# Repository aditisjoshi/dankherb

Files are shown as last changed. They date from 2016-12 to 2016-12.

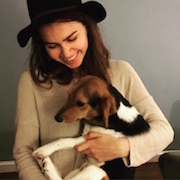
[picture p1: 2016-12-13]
website/images/ceceliaphoto.jpg

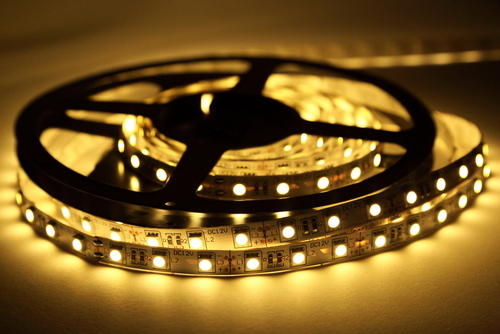
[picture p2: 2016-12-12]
website/images/lights.jpg

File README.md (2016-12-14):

# dankherb
### PoE project Fall 2016
December 6th, 2016

The following is the github repo for our final project for Principles of Engineering class Fall 2016 at Olin College of Engineering. Our project is an autonomous herb garden that takes care of your plants for you using a drip irrigation system and autonomous LED lighting system. The following are instructions for how to setup to use the project. 

## Do it yourself! (How to Run our Project)

### Getting the Code
Fork this repo. :)

### Running the Python Code (GUI)

#### dependencies 
The python GUI depends on the following libraries:

##### Python 
The code is programmed using Python 2.7. Use the instructions [here](https://www.python.org/downloads/) to download it if you do not have it.

##### Kivy
You can use `$pip install kivy` to download this package. 

###### A Note About Pygame
Kivy depends on Pygame, so if you do not have it, you can use `$pip install pygame` to download this package. 

##### Serial
You can use `$pip install pyserial` to download this package. 

#### To Run
In order to run the GUI, you must first run the Arduino code (reciever_control.ino) and then move over to python and run GardenaiApp.py. A window should appear that should give you information about the plants and their status. You can close the app when you are done with it.

##### A note about the serial name
You will need to change the name on the serial name depending on what your Arduino program names it. You should go to line 23 in the garden.py code and change the following line `ser = serial.Serial('/dev/cu.usbmodemFA131', 9600,timeout=5)` to whatever usbmodem name your Arduino has. 

### Running the Arduino Code 
In order to run the Arduino code you should run reciever_control.ino. You should attach the usb from the system into a port into your computer and change the port on your arduino IDE and then run the appropriate code. 

#### Reciever
The reciever code can be found in reciever_control.ino. This code controls everything for the water part of the system. It consists of an Arduino and an Adafruit motor shield. The motor shield controls the pump, using the Adafruit Motorshield library, by initalizing it as a motor. The four sensors that control the pump are in analog inputs 0-3. If the average of these values is below a certain threshold, then the pump turns off. 
This code also recieves control from the writer and then prints the 8 different sensor values (the 4 soil sensors and the 4 light sensors) to the serial monitor which the Python GUI code then reads to give the user the information.

#### Writer
The writer code can be found in writer_control.ino. This code controls everything for the light part of the system. The lights that we are using are individually adressable leds from Adafruit Neopixels. In order to control these we use the the Neopixel library. We are using DLI to control the lights. The code reads the light values from the four sensors in analog inputs 0-3. They take a running average of one sensor values and if that average is below the DLI threshold for that plant, the lights addressed to that plan turn on. 
This code also writes code to the reciever using the Wire library. 

## Website
The folder for the website includes the html, css, and images for the website. You can visit http://poe.olin.edu/2016/gardenai/ to see our working website in action.

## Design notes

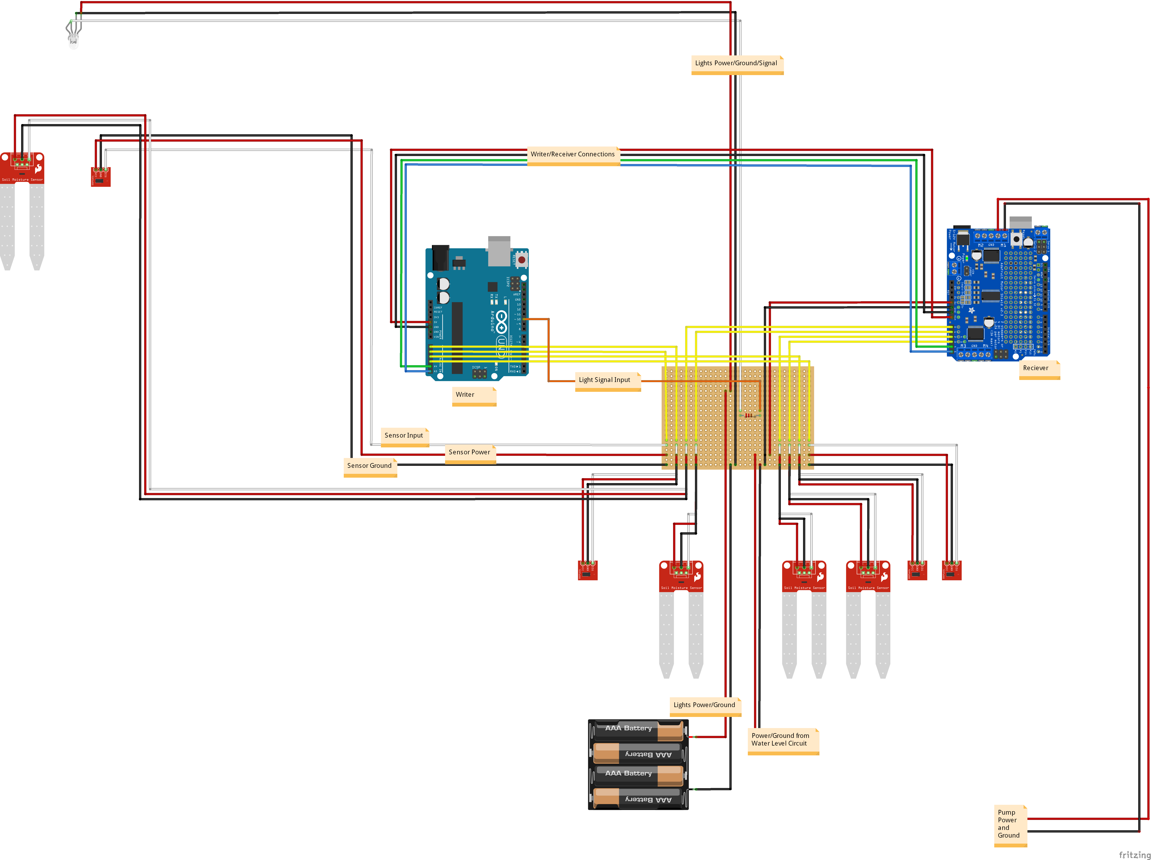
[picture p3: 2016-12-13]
website/images/overallCircuit.jpg

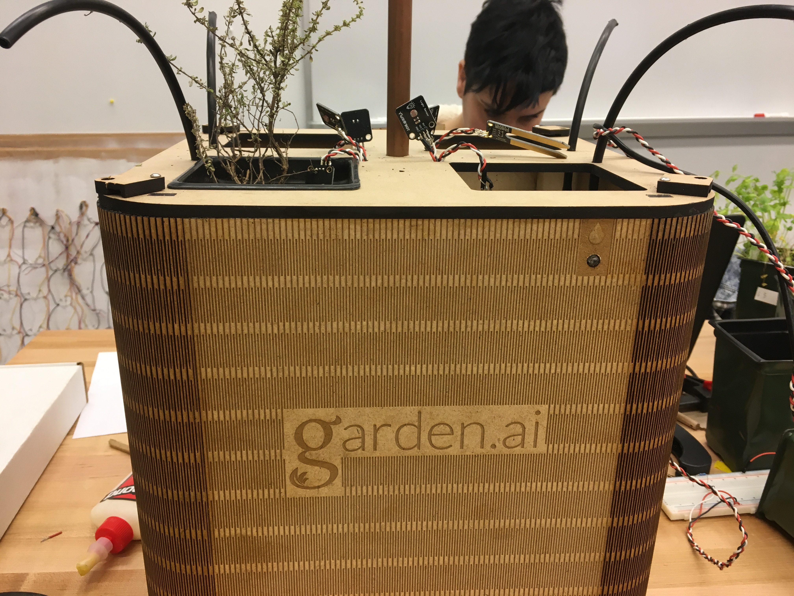
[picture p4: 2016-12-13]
website/images/gallery10.jpg

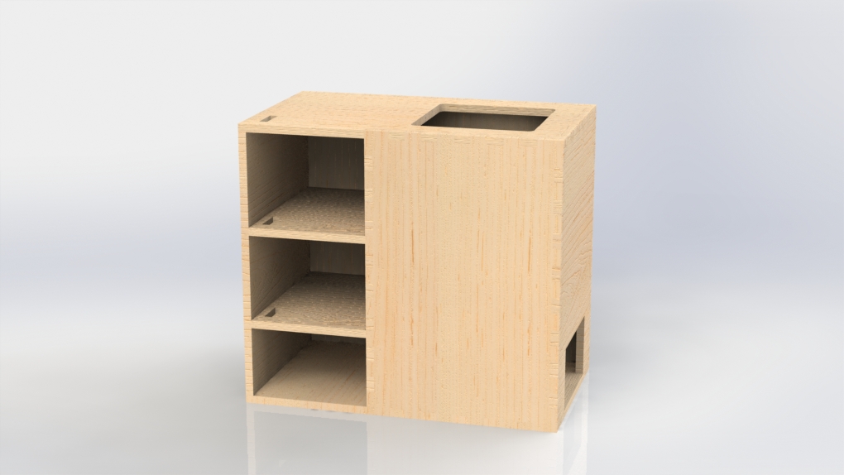
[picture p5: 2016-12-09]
website/images/gallery7.JPG

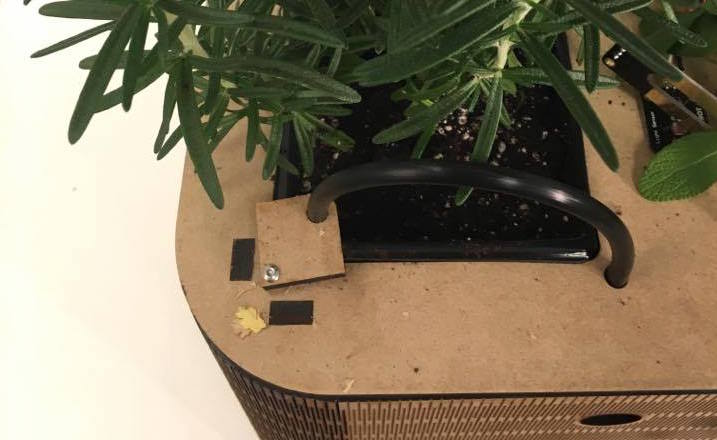
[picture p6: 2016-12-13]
website/images/irrigation.jpg

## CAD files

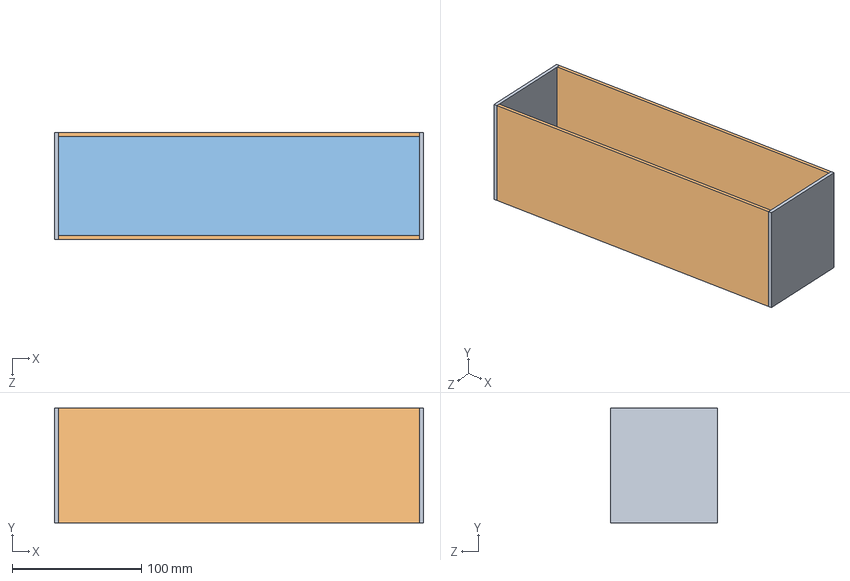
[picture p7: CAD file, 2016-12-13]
finalCadAndCutFiles/drainageresovoir/drainageresovoir.SLDASM
285.8 x 88.9 x 82.6 mm
front x 2
drsides x 2
drbottom

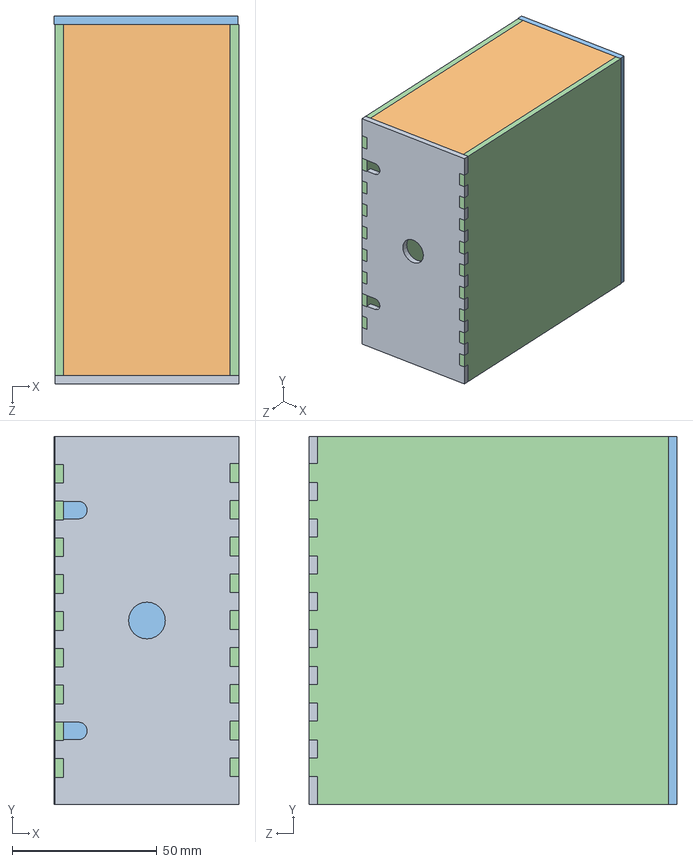
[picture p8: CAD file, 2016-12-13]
finalCadAndCutFiles/electronicsbox/elecbox.SLDASM
63.8 x 127.0 x 127.0 mm
elecfront
elecbottom x 2
elecback
elecside x 2

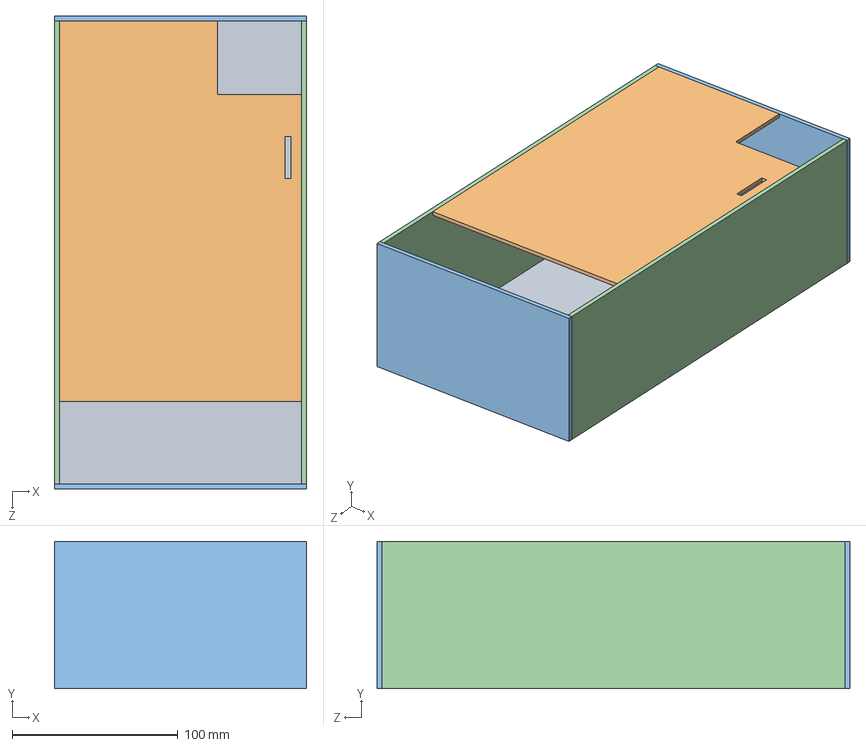
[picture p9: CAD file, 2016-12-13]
finalCadAndCutFiles/pump resovoir/pumpresovoir.SLDASM
152.4 x 88.9 x 285.8 mm
waterbottom2
top
frontandback x 2
prsides x 2

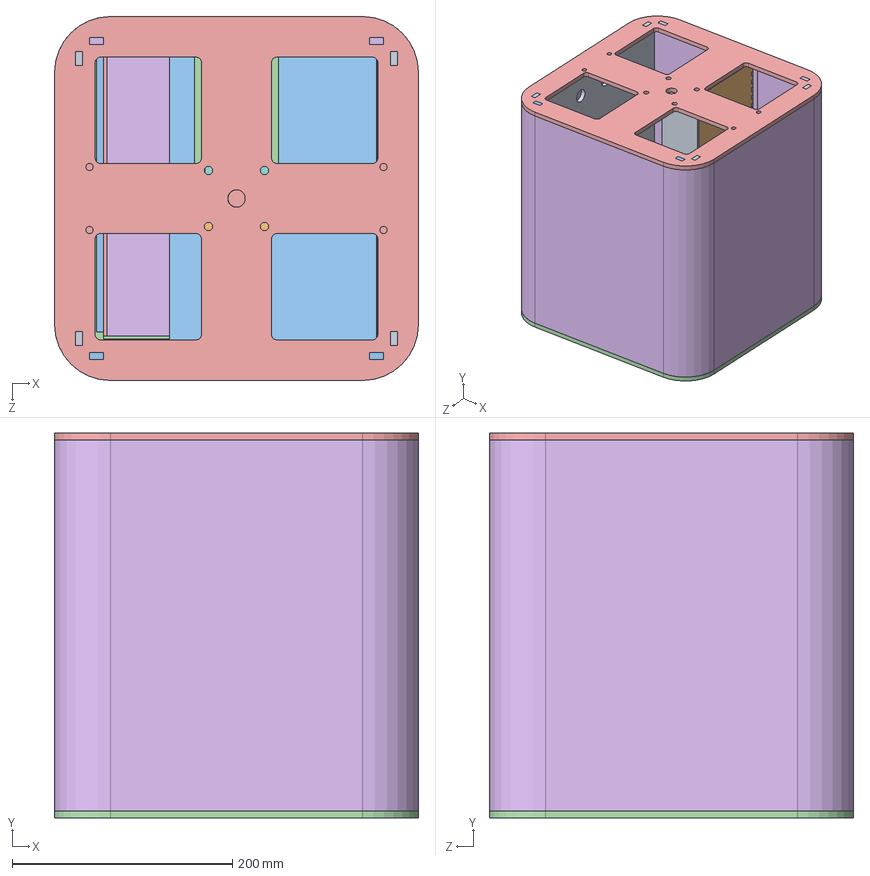
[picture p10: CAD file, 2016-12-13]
finalCadAndCutFiles/finalproto.SLDASM
330.2 x 349.2 x 330.2 mm
sidepanel2 x 2
topstrut2
slide
front x 2
drsides x 2
drbottom
waterbottom2
top
frontandback x 2
prsides x 2
dividers x 2
boxrails x 2
toppanel3
elecfront
elecbottom x 2
elecback
elecside x 2
frontpanel
bottom
bottomstrut
backpanel

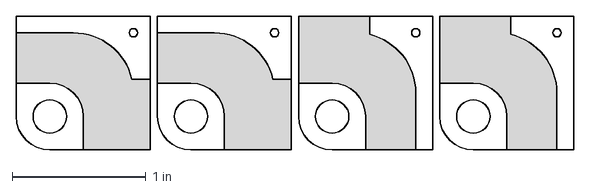
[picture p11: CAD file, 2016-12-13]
finalCadAndCutFiles/cover shade and pipe mount cut sheets/pipemount.dxf
4.16 x 1.00 in

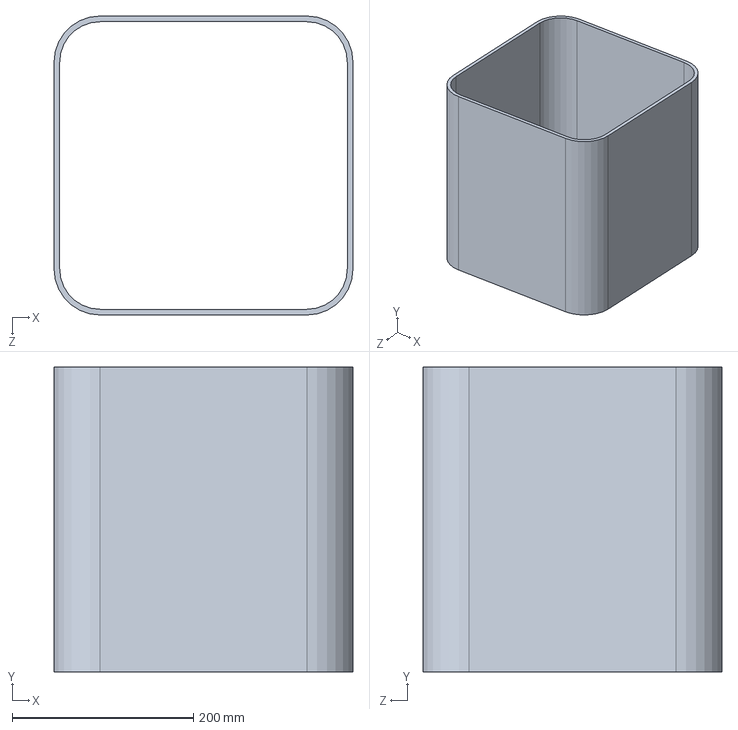
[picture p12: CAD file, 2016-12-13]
finalCadAndCutFiles/cover.SLDPRT
330.2 x 336.5 x 330.2 mm

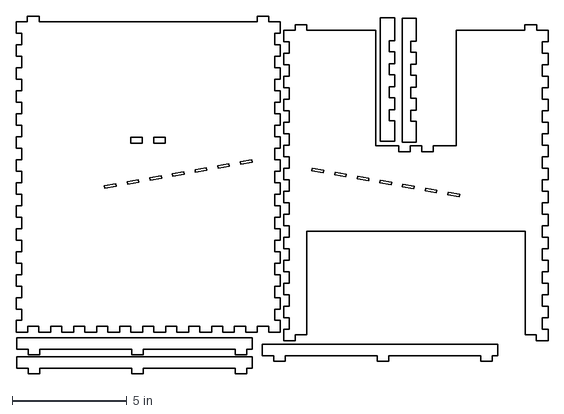
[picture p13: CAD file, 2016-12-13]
finalCadAndCutFiles/main cut sheets/1_4mdf1.DXF
23.1 x 15.6 in

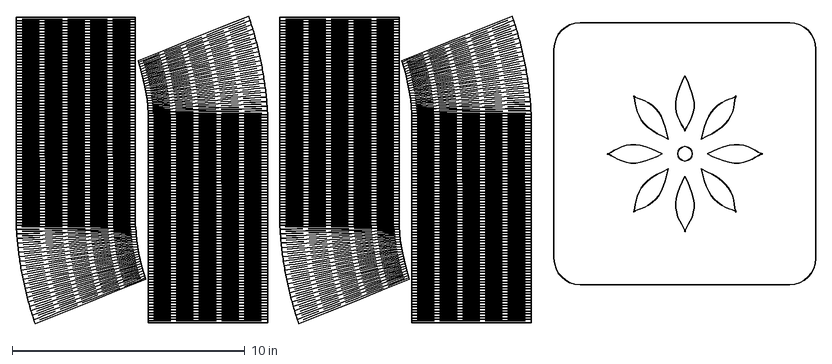
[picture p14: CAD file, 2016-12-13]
finalCadAndCutFiles/cover shade and pipe mount cut sheets/shade.dxf
34.4 x 13.2 in

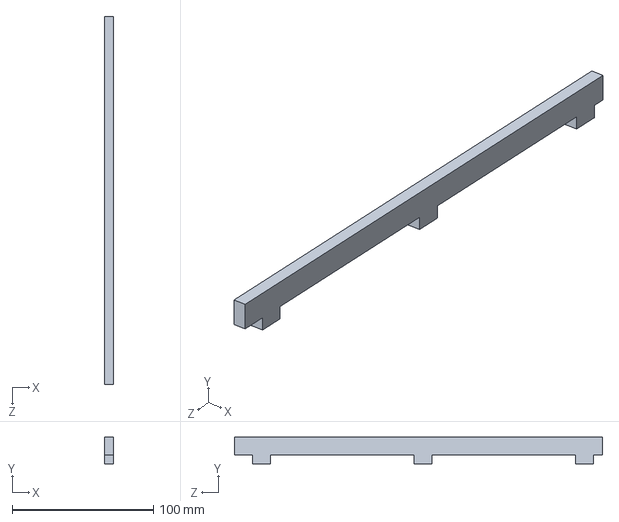
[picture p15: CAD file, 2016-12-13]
finalCadAndCutFiles/dividers.SLDPRT
6.35 x 19.1 x 260.5 mm

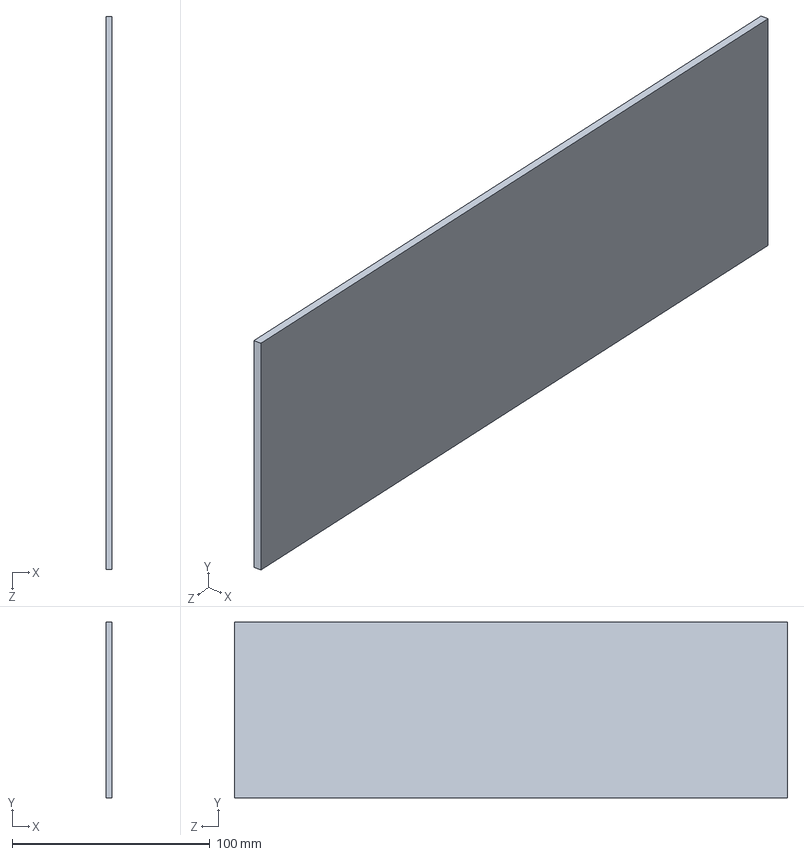
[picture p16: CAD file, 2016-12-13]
finalCadAndCutFiles/drainageresovoir/drsides.SLDPRT
3.00 x 88.9 x 279.8 mm

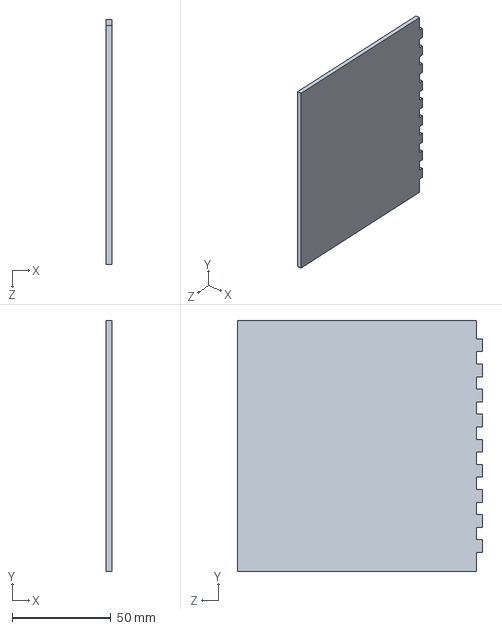
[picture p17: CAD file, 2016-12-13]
finalCadAndCutFiles/electronicsbox/elecside.SLDPRT
3.00 x 127.0 x 124.0 mm

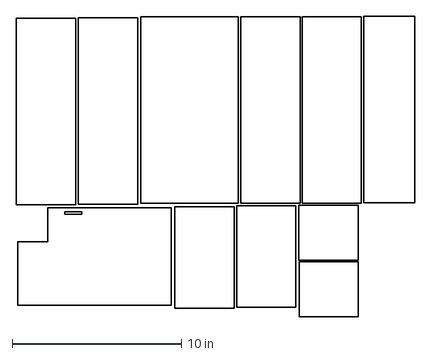
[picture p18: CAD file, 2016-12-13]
finalCadAndCutFiles/main cut sheets/118AcrylicWaterContainers.DXF
23.5 x 17.8 in

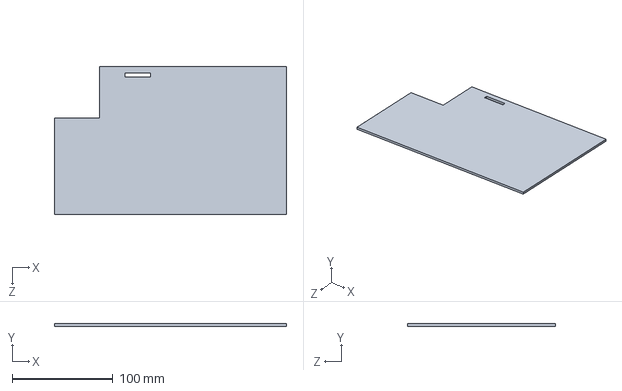
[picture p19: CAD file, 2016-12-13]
finalCadAndCutFiles/pump resovoir/top.SLDPRT
229.9 x 2.54 x 146.4 mm

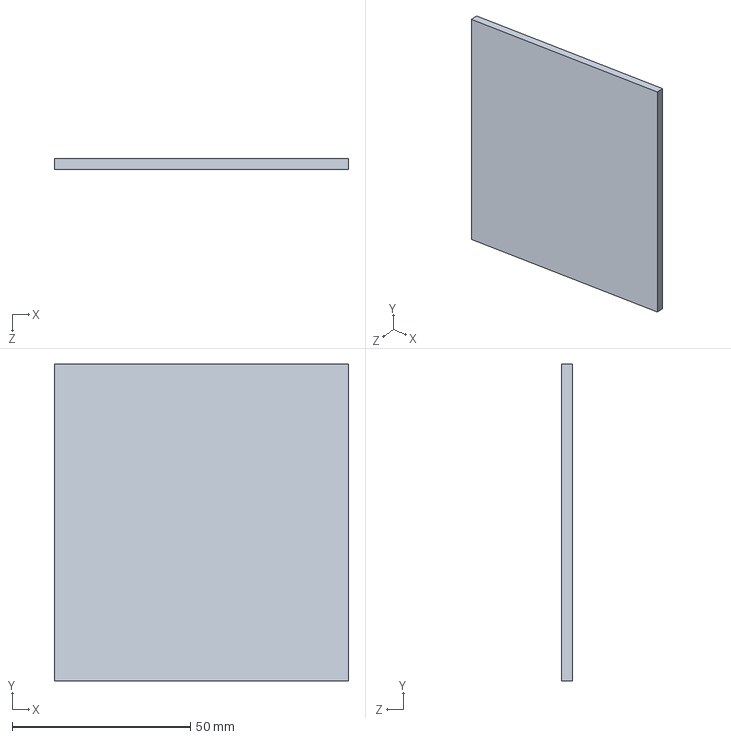
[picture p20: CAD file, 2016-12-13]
finalCadAndCutFiles/drainageresovoir/front.SLDPRT
82.5 x 88.9 x 3.00 mm

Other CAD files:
finalCadAndCutFiles/electronicsbox/elecback.SLDPRT
finalCadAndCutFiles/main cut sheets/1_4mdf2.DXF
finalCadAndCutFiles/ramp.SLDPRT
finalCadAndCutFiles/backpanel.SLDPRT
finalCadAndCutFiles/bottom.SLDPRT
finalCadAndCutFiles/bottomstrut.SLDPRT
finalCadAndCutFiles/boxrails.SLDPRT
finalCadAndCutFiles/coppertube.SLDPRT
finalCadAndCutFiles/drainageresovoir/drbottom.SLDPRT
finalCadAndCutFiles/electronicsbox/elecback.SLDDRW
finalCadAndCutFiles/electronicsbox/elecbottom.SLDPRT
finalCadAndCutFiles/electronicsbox/elecfront.SLDPRT
finalCadAndCutFiles/frontpanel.SLDPRT
finalCadAndCutFiles/lightmount.SLDPRT
finalCadAndCutFiles/main cut sheets/118AcrylicRampAndBox.DXF
finalCadAndCutFiles/main cut sheets/1_4mdf3.DXF
finalCadAndCutFiles/main cut sheets/1_4mdf4.DXF
finalCadAndCutFiles/main cut sheets/finalcutsheets.SLDDRW
finalCadAndCutFiles/pump resovoir/frontandback.SLDPRT
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

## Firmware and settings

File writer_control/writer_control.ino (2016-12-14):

// adding in the necessary libraries
#include <Wire.h>
#include <Adafruit_NeoPixel.h>

// chosing the pins that the lights are attached too
#define PIN     8
#define N_LEDS  20


//set up for Neopixels
Adafruit_NeoPixel strip = Adafruit_NeoPixel(N_LEDS, PIN, NEO_GRB + NEO_KHZ800);

int lightSensorVal1;
int lightSensorPin1 = A3;
int lightSensorVal2;
int lightSensorPin2 = A2;
int lightSensorVal3;
int lightSensorPin3 = A1;
int lightSensorVal4;
int lightSensorPin4 = A0;

// these are the indices of the individually addressable LEDs that should be turned on for each light
int numLights[] = {0 , N_LEDS / 4, (2 * N_LEDS) / 4, (3 * N_LEDS) / 4,  (4 * N_LEDS) / 4};


//sensor val to lux calibration values
const float a = -6.04174634356 * pow(10, -14);
const float b = 1.73210693561 * pow(10, -10);
const float c = -1.80136355915 * pow(10, -7);
const float d = 8.6163611226 * pow(10, -5);
const float e = -0.0191817214905;
const float f = 1.80117265067;
const float g = -42.2194133246;

//conversion constants for lux -> ppfd -> dli
const float ppfdConversionConstant = 0.029; //Sunlight 0.0185, Fluorescent (Grolux) 0.029
const float dliConversionConstant = 0.0864; //The 0.0864 factor is the total number of seconds in a day divided by 1,000,000 (to convert umol to mol)

//adding up lux to get daily light integral (DLI)
float dailyLuxVals[4][24];

int hour = 0;
int tStartHour;
int tCurrent;
const int oneHour = 3.6 * pow(10, 6); //one hour in milliseconds
int currentLuxVal;

float currentDLI;
float currentDLISaved[4];

const float minDLI = 0.5;
const float maxDLI = 0.9;

void setup() {
  // put your setup code here, to run once:
  Wire.begin();
  Serial.begin(9600);
  strip.begin();
}

void loop() {
  updateLights();
  controlLights();
  sendDatatoReceiver();
}


//setup functions

//writer functions

void sendDatatoReceiver() {
  //sends the DLI data to the receiver, from which it is printed to the serial, where the python GUI can grab it
  Wire.beginTransmission(8);
  Wire.write("a");
  Wire.write((int)currentDLISaved[0]);
  Wire.write("b");
  Wire.write((int)currentDLISaved[1]);
  Wire.write("c");
  Wire.write((int)currentDLISaved[2]);
  Wire.write("d");
  Wire.write((int)currentDLISaved[3]);
  Wire.endTransmission();

  delay(100);
}

//CONTROL THE LIGHTS FUNCTIONS

void controlLights() {
  //for each light, get the current DLI, and if it is not bright enough, turn the lights on

  for (int lightNum = 0; lightNum < 4; lightNum++) {
    currentDLI = getDLI(lightNum);
    currentDLISaved[lightNum] = currentDLI; //save this so that we can send it to the python GUI
    if (minDLI < currentDLI && currentDLI < maxDLI) {
      chase(strip.Color(0, 0, 0), numLights[lightNum], numLights[lightNum + 1]);
    } else {
      chase(strip.Color(255, 255, 255), numLights[lightNum], numLights[lightNum+1]); // Red
    }
  }
}

static void chase(uint32_t c, int numstart, int numend) {
  for (uint16_t i = numstart; i < numend; i++) {
    strip.setPixelColor(i  , c); // Draw new pixel
    strip.show();
  }
}

//UPDATE FUNCTIONS

void updateLights() {
  //updateTime() returns true if an hour has passed, false if not
  //this saves the sensor light values every hour so that the average can be calculated

  if (updateTime()) {
    updateDailyLightValues(0, lightSensorPin1);
    updateDailyLightValues(1, lightSensorPin2);
    updateDailyLightValues(2, lightSensorPin3);
    updateDailyLightValues(3, lightSensorPin4);
  }
}

boolean updateTime() {
  //returns true if an hour has passed, false if not

  tCurrent = millis();
  //if an hour has passed
  if ((tCurrent - tStartHour) >= 500) {
    //update the start of the hour
    tStartHour = tCurrent;
    // update the hour number we are on
    if (hour == 24) {
      hour = 0;
    }
    else {
      hour++;
    }
    //update the daily light values
    return true;
  }

  return false;
}

void updateDailyLightValues(int sensorNum, int sensorPin) {
  //gets the current light value in Lux from the value given by the sensor and adds it to the average of the day's values
  currentLuxVal = sensorToLux(getSensorVal(sensorPin));
  addLuxtoAverage(sensorNum, currentLuxVal);
}

float addLuxtoAverage(int sensorNum, float luxVal) {
  dailyLuxVals[sensorNum][hour] = luxVal;
}

//GET KEY VALUES FUNCTIONS

int getSensorVal(int pin) {
  int sensorVal = analogRead(pin);
  return sensorVal;
}

float getDLI(int sensorNum) {
  //for a certain sensor (i.e. a certain plant), get the average lux from the last 12 hours and convert that to PPFD and then DLI
  //(see our website resources for more info on PPFD and DLI)
  return ppfdToDLI(avgLuxToPPFD(getLuxAverage(sensorNum))); //is this a cool thing to do with arduino? #notpython
}

float sum;
float getLuxAverage(int sensorNum) {
  //takes average of all saved lux values from the last 12 hours
  sum = 0;
  float numVals = 24.0;
  for (int i = 0; i < 24; i++) {
    int dailyLightVal = dailyLuxVals[sensorNum][i];
    sum += dailyLightVal;
  }

  return ((float)sum) / numVals;
}

//CONVERSION FUNCTIONS

float sensorToLux(int sensorVal) {
  //this polynomial comes from our own calibration of the sensor
  return a * pow(sensorVal, 6) + b * pow(sensorVal, 5) + c * pow(sensorVal, 4) + d * pow(sensorVal, 3) + e * pow(sensorVal, 2) + f * pow(sensorVal, 1) + g;
}

float avgLuxToPPFD(float luxVal) {
  return luxVal * ppfdConversionConstant; //PPFD in µmol m-2 s-1
}

float ppfdToDLI(float ppfdVal) {
  return ppfdVal * dliConversionConstant;
}

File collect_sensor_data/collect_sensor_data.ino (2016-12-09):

#include <Adafruit_NeoPixel.h>

#define PIN     10
#define N_LEDS  20

Adafruit_NeoPixel strip = Adafruit_NeoPixel(N_LEDS, PIN, NEO_GRB + NEO_KHZ800);


int soilSensorVal1;
int soilSensorPin1 = A0;

int lightSensorVal1;
int lightSensorPin1 = A1;

int soilSensorVal2;
int soilSensorPin2 = A2;

int lightSensorVal2;
int lightSensorPin2 = A3;

int soilSensorVal3;
int soilSensorPin3 = A4;

int lightSensorVal3;
int lightSensorPin3 = A5;

// NEED TO FIX THESE PINS 
int soilSensorVal4;
int soilSensorPin4 = A2;

int lightSensorVal4;
int lightSensorPin4 = A3;

int pumpPin = 8;

//int numstart;
//int numend;

int num1 = N_LEDS / 4;
int num2 = (2 * N_LEDS) / 4;
int num3 = (3 * N_LEDS) / 4;
int num4 = (4 * N_LEDS) / 4;



void setup() {
  pinMode(pumpPin, OUTPUT);      // sets the digital pin as output
  strip.begin();
  // put your setup code here, to run once:
  Serial.begin(9600); 
}

void loop() {
  // put your main code here, to run repeatedly:
  // this code reads the different light and soil sensor values for all of the plants 
  soilSensorVal1 = analogRead(soilSensorPin1);
  lightSensorVal1 = analogRead(lightSensorPin1);

  soilSensorVal2 = analogRead(soilSensorPin2);
  lightSensorVal2 = analogRead(lightSensorPin2);

  soilSensorVal3 = analogRead(soilSensorPin3);
  lightSensorVal3 = analogRead(lightSensorPin3);

  soilSensorVal4 = analogRead(soilSensorPin4);
  lightSensorVal4 = analogRead(lightSensorPin4);

  
  // this is the control code for the lights
  if (lightSensorVal1 < 950) {

    chase(strip.Color(255, 255, 255) num1); // Red
  } else {
    chase(strip.Color(0, 0, 0) num1);
  }

  if (lightSensorVal1 < 950) {
    chase(strip.Color(255, 255, 255) num1); // Red
  } else {
    chase(strip.Color(0, 0, 0) num1);
  }

  if (lightSensorVal1 < 950) {
    chase(strip.Color(255, 255, 255) num1); // Red
  } else {
    chase(strip.Color(0, 0, 0) num1);
  }

  if (lightSensorVal1 < 950) {
    chase(strip.Color(255, 255, 255) num1); // Red
  } else {
    chase(strip.Color(0, 0, 0) num1);
  }



  // this is the control code for the water NEEDS TO BE FIXED
  if (soilSensorVal1 < 800) {
    digitalWrite(pumpPin, HIGH);   // sets the LED on
  } else {
    digitalWrite(pumpPin, LOW);   // sets the LED on
  }


  // this is the printing of the sensor values (used by the GUI to be read from the serial monitor)
  Serial.print(lightSensorVal1);
  Serial.print("/");
  Serial.println(soilSensorVal1);
  Serial.print("/");
  Serial.print(lightSensorVal2);
  Serial.print("/");
  Serial.println(soilSensorVal2);
  Serial.print("/");
  Serial.print(lightSensorVal3);
  Serial.print("/");
  Serial.println(soilSensorVal3);
  Serial.print("/");
  Serial.print(lightSensorVal4);
  Serial.print("/");
  Serial.println(soilSensorVal4);
}


<<<<<<< Updated upstream
static void chase(uint32_t c, int numstart, int numend) {
  for(uint16_t i=numstart; i<numend; i++) {
=======
static void chase(uint32_t c num) {
  for(uint16_t i=0; i<num; i++) {
>>>>>>> Stashed changes
      strip.setPixelColor(i  , c); // Draw new pixel
      strip.show();
  }
} 

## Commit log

2016-10-23 Collects data from the arduino and uses fake threshold values determine the status of the plants
2016-10-23 Adding arduino code for collecting data from sensors
2016-10-26 EDIT: threshold values for soil sensor
2016-11-04 ADD: code that takes in light sensor data and turns on a strip of LEDS when its not bright enough
2016-11-07 changing sensor code and gui to include both plants
2016-11-07 fixing the integration between gui and arduino
2016-11-08 fixing the soil_status and light_status to not be TEST
    [GardenaiApp.py, garden.py, plant.py]
2016-11-11 EDIT: code works with arduino for lights and with gui
2016-11-16 fixing light control code
    [collect_sensor_data.ino]
2016-11-18 fixing type error for serial printing
    [receiver_control.ino, writer_control.ino]
2016-11-29 UPDATE: light calibration and debugged code
2016-11-30 ADD: pump code for arduino:
2016-11-30 adding in water level sensor info
    [poe.fzz]
2016-11-30 fixing water control code
    [receiver_control.ino]
2016-11-30 changing pump on rate
2016-12-11 adding in refresh button to GUI
2016-12-12 ADD: circuit diagram images to electrical page
2016-12-13 adding cad files
    woot
    [118AcrylicRampAndBox.DXF, 118AcrylicWaterContainers.DXF, 1_4mdf1.DXF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]
2016-12-13 EDIT: mechanical page to include CAD and john's edits
2016-12-14 changing motor controller
2016-12-14 ADD: new calibration values, more comments, etc.)
